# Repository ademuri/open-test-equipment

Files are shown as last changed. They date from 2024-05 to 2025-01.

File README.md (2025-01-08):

## usb-c-banana-adapter

Adapter board for a USB-C downstream-facing port (DFP). This allow supplying
power over USB-C using a lab power supply with banana jack outputs. The USB
port uses 10k pullups on the CC pins to indicate that it can supply 5V at 3A.
Note that this does **not** follow the USB-C spec - the spec requires that a
DFP only enable power on VBUS once the DFP has confirmed a device is plugged in
by reading the voltage divider on the CC channels.

## usb-c-banana-with-data

Similar to the above, but has two USB-C ports - one upstream and one downstream
port. The data lines are connected between the ports, but power is not. Power is
injected into the DFP from banana jacks. This is useful for measuring the
conducted emissions of a USB device with a DC LISN, while sending data over USB
as well.

### USB trace impedance

Given a two-layer board and the connector geometry, it's difficult to make the USB traces have the 45Ω impedance as per the USB spec. With a trace width of 0.3mm and a (best-case) spacing of 0.2mm, and a ground plane on the other side of the 1.6mm board, the impedance is around 45Ω. The traces are within 0.5mm length of each other, with a total length of ~13mm and ~14mm for the two USB pairs. This all is probably good enough, at least for full-speed USB (12Mbps).

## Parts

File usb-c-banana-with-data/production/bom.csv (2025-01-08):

Designator | Footprint | Quantity | Value | LCSC Part #
D1, D2 | 0603 | 2 | LED | C2286
J1, J4 | HRO_TYPE-C-31-M-12 | 2 | TYPE-C-31-M-12 | C165948
J2, J3 | Banana_Jack_1Pin | 2 | Conn_01x01 | Keystone 575-8
R1, R2 | 0603 | 2 | 10k | C25804
R3, R4 | 0603 | 2 | 5k1 | C23186
R5, R6 | 0603 | 2 | 1k | C21190

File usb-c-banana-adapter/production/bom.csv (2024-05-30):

Designator | Footprint | Quantity | Value | LCSC Part #
J1 | HRO_TYPE-C-31-M-12 | 1 | TYPE-C-31-M-12 | C165948
J2, J3 | Banana_Jack_1Pin | 2 | Conn_01x01 | C4994335
R1, R2 | 0603 | 2 | 10k | C25804

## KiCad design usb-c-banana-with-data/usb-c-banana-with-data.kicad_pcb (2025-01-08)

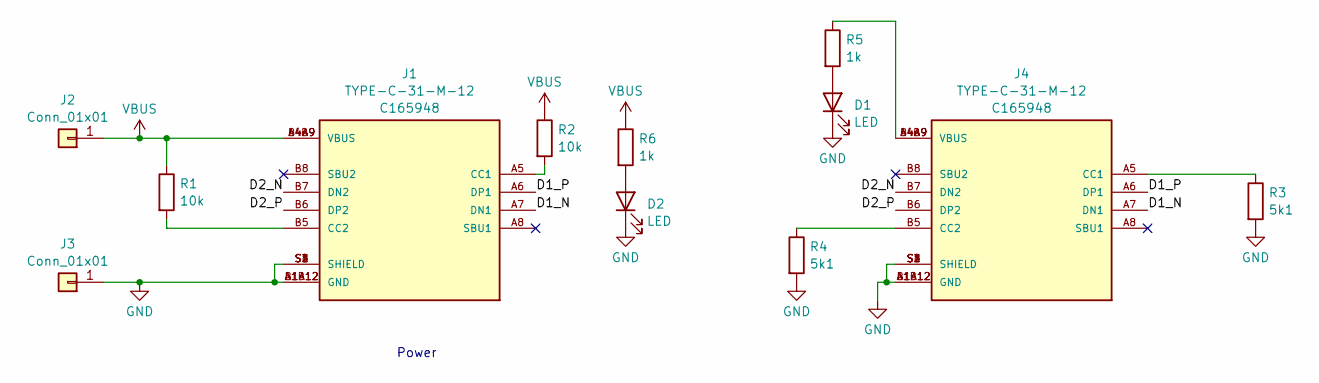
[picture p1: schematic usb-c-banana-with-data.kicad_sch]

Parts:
D1, D2: LED; LED_0603_1608Metric_Pad1.05x0.95mm_HandSolder; LCSC C2286
J1, J4: TYPE-C-31-M-12; HRO_TYPE-C-31-M-12; PARTREV A; LCSC C165948
J2, J3: Conn_01x01; Banana_Jack_1Pin; MPN Keystone 575-8
R1, R2: 10k; R_0603_1608Metric_Pad0.98x0.95mm_HandSolder; LCSC C25804
R3, R4: 5k1; R_0603_1608Metric_Pad0.98x0.95mm_HandSolder; LCSC C23186
R5, R6: 1k; R_0603_1608Metric_Pad0.98x0.95mm_HandSolder; LCSC C21190

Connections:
/D1_N: J1.A7 (DN1), J4.A7 (DN1)
/D1_P: J1.A6 (DP1), J4.A6 (DP1)
/D2_N: J1.B7 (DN2), J4.B7 (DN2)
/D2_P: J1.B6 (DP2), J4.B6 (DP2)
GND: D1.1 (K), D2.1 (K), J1.A1B12 (GND), J1.B1A12 (GND), J1.S1 (SHIELD), J1.S2 (SHIELD), J1.S3 (SHIELD), J1.S4 (SHIELD), J3.1, J4.A1B12 (GND), J4.B1A12 (GND), J4.S1 (SHIELD), J4.S2 (SHIELD), J4.S3 (SHIELD), J4.S4 (SHIELD), R3.2, R4.2
unnamed: D1.2 (A), R5.2
unnamed: D2.2 (A), R6.2
unnamed: J1.A5 (CC1), R2.2
unnamed: J1.B5 (CC2), R1.2
unnamed: J4.A5 (CC1), R3.1
unnamed: J4.B5 (CC2), R4.1
unnamed: J4.A4B9 (VBUS), J4.B4A9 (VBUS), R5.1
VBUS: J1.A4B9 (VBUS), J1.B4A9 (VBUS), J2.1, R1.1, R2.1, R6.1

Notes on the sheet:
Power

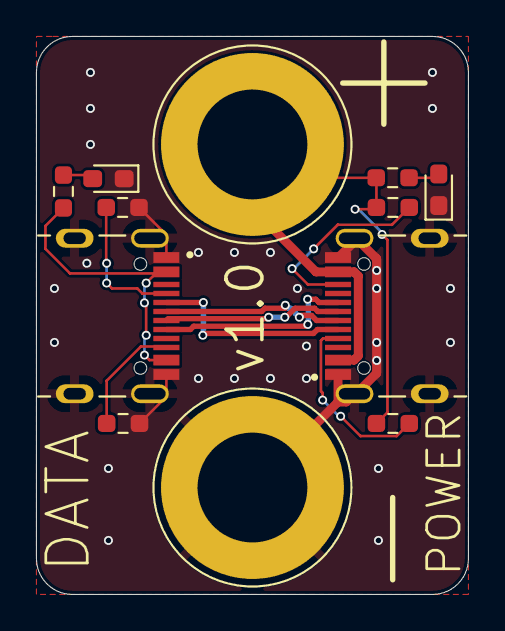
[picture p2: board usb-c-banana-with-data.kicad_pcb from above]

Board: 2 copper layers, 24.0 x 31.0 mm, 12 parts (0 on the bottom side), 13 nets.

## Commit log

2024-05-30 Add gitignore for KiCAD temp files
2024-05-30 Add usb-c-banana-adapter v1.0
    [bom.csv, designators.csv, positions.csv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]
2024-05-30 Update for usb-c-banana-adapter v1.0
    [positions.csv, usb-c-banana-adapter.kicad_pcb]
2025-01-07 rf-wallpaper: fix resistance grid
2025-01-08 rf-wallpaper: draw capacitor lines
2025-01-08 WIP start routing banana-with-data
    [usb-c-banana-with-data.kicad_pcb, usb-c-banana-with-data.kicad_sch]
2025-01-08 usb-c-banana-with-data: hardware v1.0
    [bom.csv, designators.csv, positions.csv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]
2025-01-08 rf-wallpaper: add minor capacitance lines
2025-01-09 rf-wallpaper: add minor highlighting for resistance
2025-01-09 rf-wallpaper: simplify capacitance lines to use a single loop
2025-01-09 rf-wallpaper: display frequency and resistance values
2025-01-09 rf-wallpaper: add capacitance and inductance value display
2025-01-09 Add capacitance highlighting
